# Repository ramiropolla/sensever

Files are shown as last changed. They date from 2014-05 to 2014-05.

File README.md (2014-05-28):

sensever
========

O projeto consiste em 17 tablados com sensores piezo-elétricos.

<pre>
      Esquemático dos tablados
                _____
               /     \
         _____/   5   \_____
        /     \       /     \
       /  13   \_____/   9   \
       \       /     \       /
        \_____/   4   \_____/
        /     \       /     \
  _____/  12   \_____/   8   \_____
 /     \       /     \       /     \
/  17   \_____/   3   \_____/  15   \
\       /     \       /     \       /
 \_____/  11   \_____/   7   \_____/
 /     \       /     \       /     \
/  16   \_____/   2   \_____/  14   \
\       /     \       /     \       /
 \_____/  10   \_____/   6   \_____/
       \       /     \       /
        \_____/   1   \_____/
              \       /
               \_____/
</pre>

A leitura dos sensores é feita com 4 placas Arduino distribuidas entre os
tablados. Os Arduinos estão nas placas 2, 4, 14 e 16, de forma a otimizar
o caminho de comunicação do circuito. A placa de número 4 está ligada pela
USB ao PC que controla o circuito. A placa 4 também está ligada à placa 2,
que por sua vez está ligada às placas 14 e 16.

<pre>
Esquemático de comunicação dos Arduinos
    ______
   |      |
   |  PC  |
   |______|
           \    _____
            \  /     \
         ____\/   5   \_____
        /     \       /     \
       /  13   \_____/   9   \
       \       /\_   \       /
        \_____/   4   \_____/
        /     \   |   /     \
  _____/  12   \__|__/   8   \_____
 /     \       /  |  \       /     \
/  17   \_____/   3   \_____/  15   \
\       /     \   |   /     \       /
 \_____/  11   \__|__/   7   \_____/
 /     \       /  |  \       /     \
/  16__ \_____/   2   \_____/ _14   \
\      \/     \__/ \__/     \/      /
 \_____/\_10__/\_____/\__6__/\_____/
       \       /     \       /
        \_____/   1   \_____/
              \       /
               \_____/
</pre>

Para evitar que o ruído da rede elétrica influencie na leitura dos sensores
piezo-elétricos, é utilizado um circuito opto-isolador na placa 4. Assim,
a placa 4 tem um cabo denominado 'PC', que deve ser ligado ao computador,
e outro cabo denominado 'Tomada', que deve ser ligado em alguma fonte USB
que não apresente ruído, como um Power Bank USB ou um computador com a
bateria carregada e que não esteja ligado na tomada.

Cada sensor piezo-elétrico está ligado ao Arduino mais próximo.

No Arduino 2 estão ligadas as placas 1, 3, 6, 7, 10 e 11.

No Arduino 4 estão ligadas as placas 5, 8, 9, 12 e 13.

No Arduino 14 está ligada a placa 15.

No Arduino 16 está ligada a placa 17.

<pre>
 Esquemático de sensores por Arduino
                _____
               /     \
         _____/   5   \_____
        /     \   |   /     \
       /  13__ \__|__/ __9   \
       \      \/  |  \/      /
        \_____/\__4__/\_____/
        /     \/     \/     \
  _____/  12__/\_____/\__8   \_____
 /     \       /     \       /     \
/  17   \_____/   3   \_____/  15   \
\   |   /     \   |   /     \   |   /
 \__|__/  11__ \__|__/ __7   \__|__/
 /  |  \      \/  |  \/      /  |  \
/  16   \_____/\__2__/\_____/  14   \
\       /     \/  |  \/     \       /
 \_____/  10__/\__|__/\__6   \_____/
       \       /  |  \       /
        \_____/   1   \_____/
              \       /
               \_____/
</pre>

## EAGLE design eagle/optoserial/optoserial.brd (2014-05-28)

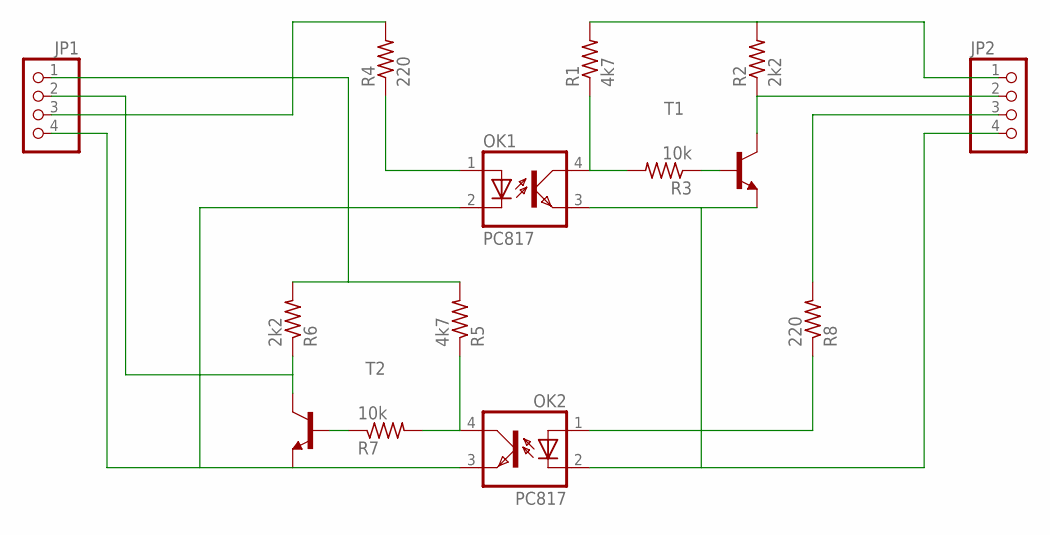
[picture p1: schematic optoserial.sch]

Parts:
JP1, JP2: PINHD-1X4; 1X04
OK1, OK2: PC817; DIL04
R1, R5: 4k7; 0207/10
R2, R6: 2k2; 0207/10
R3, R7: 10k; 0207/10
R4, R8: 220; 0207/10
T1, T2: 2N2222-NPN-TO92-EBC; TO92-EBC

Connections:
unnamed: JP2.1, R1.2, R2.2
unnamed: OK1.4 (COL), R1.1, R3.2
unnamed: JP2.4, OK1.3 (EMIT), OK2.2 (C), T1.E
unnamed: R3.1, T1.B
unnamed: JP2.2, R2.1, T1.C
unnamed: OK1.1 (A), R4.1
unnamed: JP1.1, R5.2, R6.2
unnamed: OK2.4 (COL), R5.1, R7.2
unnamed: JP1.4, OK1.2 (C), OK2.3 (EMIT), T2.E
unnamed: R7.1, T2.B
unnamed: JP1.2, R6.1, T2.C
unnamed: OK2.1 (A), R8.1
unnamed: JP1.3, R4.2
unnamed: JP2.3, R8.2

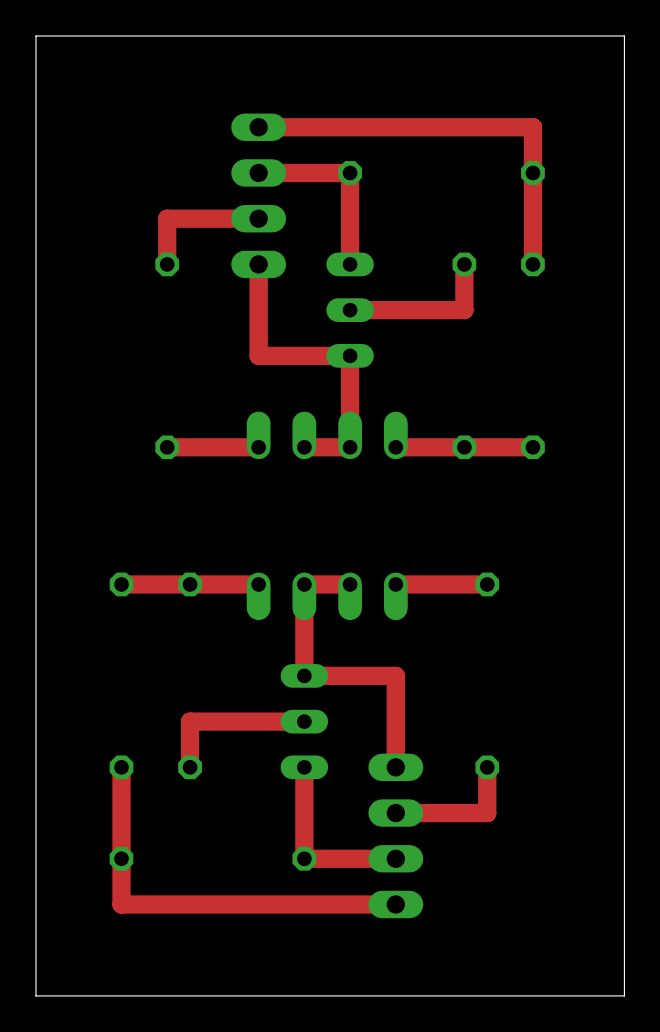
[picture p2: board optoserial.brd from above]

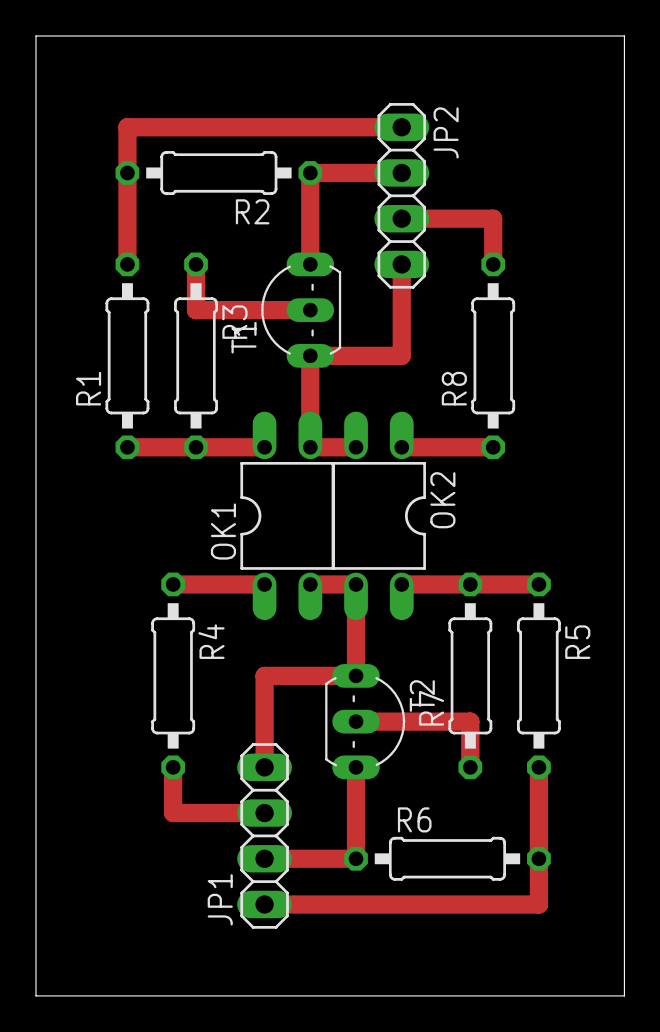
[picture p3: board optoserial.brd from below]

Board: 2 copper layers, 32.7 x 53.3 mm, 14 parts (14 on the bottom side), 14 nets.

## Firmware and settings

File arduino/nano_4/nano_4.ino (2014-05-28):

#include <SoftwareSerial.h>

// software serial #1: TX = digital pin 2, RX = digital pin 3
static SoftwareSerial serial2(2, 3);

#define N_LEITURAS 8
#define BAUDRATE 19200

void setup()
{
    Serial.begin(4800); /* opto-isolador */
    serial2.begin(BAUDRATE);
}

struct sensor_t {
    uint8_t  sensor;
    SoftwareSerial *serial;
    uint16_t soma;
};

static struct sensor_t sensores[] = {
    /*  0 */    {  0 },
    /*  1 */    {  0, &serial2 },
    /*  2 */    {  0, &serial2 },
    /*  3 */    {  0, &serial2 },
    /*  4 */    { A4 }, /* OK */
    /*  5 */    { A1 }, /* OK */
    /*  6 */    {  0, &serial2 },
    /*  7 */    {  0, &serial2 },
    /*  8 */    { A5 }, /* OK */
    /*  9 */    { A3 }, /* OK */
    /* 10 */    {  0, &serial2 },
    /* 11 */    {  0, &serial2 },
    /* 12 */    { A6 }, /* OK */
    /* 13 */    { A2 }, /* OK */
    /* 14 */    {  0, &serial2 },
    /* 15 */    {  0, &serial2 },
    /* 16 */    {  0, &serial2 },
    /* 17 */    {  0, &serial2 },
};

static struct sensor_t *leituras[] = {
    &sensores[ 4],
    &sensores[ 5],
    &sensores[ 8],
    &sensores[ 9],
    &sensores[12],
    &sensores[13],
};

static void check_serial()
{
    while (Serial.available()) {
        uint8_t c = Serial.read();
        c -= '0';
        if (c <= sizeof(sensores)/sizeof(sensores[0])) {
            if        (sensores[c].sensor) {
                if (sensores[c].soma > 0xff)
                    sensores[c].soma = 0xff;
                Serial.write(sensores[c].soma);
            } else if (sensores[c].serial) {
                SoftwareSerial *s = sensores[c].serial;
                unsigned long t0;
                s->listen();
                s->write((uint8_t) c + '0');
                t0 = millis();
                while (!s->available() && (millis() - t0) < 200);
                if (s->available()) {
                    Serial.write(s->read());
                } else {
                    Serial.write((uint8_t) 0x00);
                }
            } else {
                Serial.write((uint8_t) 0x00);
            }
        } else {
            Serial.write((uint8_t) 0x00);
        }
    }
}

void loop()
{
    for (uint8_t i = 0; i < sizeof(leituras)/sizeof(leituras[0]); i++) {
        struct sensor_t *s = leituras[i];
        if (s->sensor) {
            unsigned long t0;
            analogRead(s->sensor);
            t0 = millis();
            while (millis() < (t0+10))
                check_serial();
            s->soma = 0;
            for (uint8_t j = 0; j < N_LEITURAS; j++)
                s->soma += analogRead(s->sensor);
        }
    }
}

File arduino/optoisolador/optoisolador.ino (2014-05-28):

#include <SoftwareSerial.h>

// software serial #1: RX = digital pin 2, TX = digital pin 3
static SoftwareSerial serial2(2, 3);

#define BAUDRATE 19200

void setup()
{
    Serial.begin(BAUDRATE);
    serial2.begin(4800); /* opto-isolador */
}

void loop()
{
    if (Serial.available())
        serial2.write(Serial.read());
    if (serial2.available())
        Serial.write(serial2.read());
}

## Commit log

2014-05-28 atualizar arquivos de arduino
2014-05-28 sketchbook -> arduino
2014-05-28 optoserial: adicionar esquemáticos do eagle
    [optoserial.brd, optoserial.sch]
2014-05-28 adicionar explicação dos arduinos
